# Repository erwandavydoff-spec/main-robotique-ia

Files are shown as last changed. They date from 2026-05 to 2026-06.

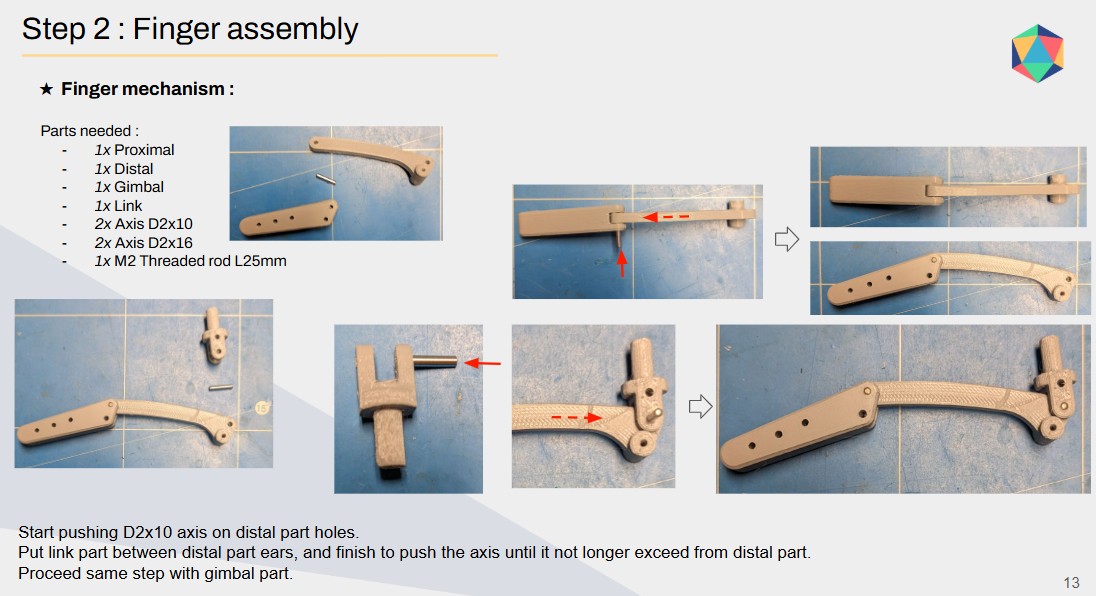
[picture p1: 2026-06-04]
assets/Assembly.jpg

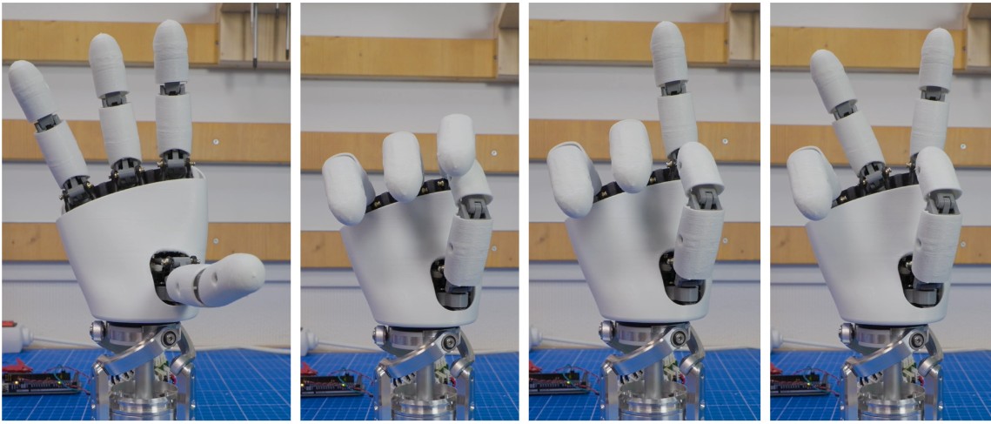
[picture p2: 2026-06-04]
assets/Patterns_Overview.jpg

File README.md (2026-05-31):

<div align="center">

Header

**Open-source robotic hand controlled by real-time AI hand tracking**









</div>

---

## Overview

**Main Robotique IA** is a fully functional robotic hand that replicates human finger movements in real time using a standard webcam and AI-based hand tracking.

A camera captures the user's hand. MediaPipe detects 21 3D landmarks on it. Python computes the flexion angle of each finger and sends the result to an ESP32 microcontroller over USB serial. The ESP32 drives five servo motors — one per finger — to mirror the gesture with minimal latency.

No cloud. No external API. Everything runs locally on consumer hardware.

> **Current state:** the full pipeline is operational end-to-end. The hand successfully replicates gestures captured by the camera in real time. Active work is focused on latency reduction, mechanical refinement, and auto-calibration.

---

## Demo

| Gesture captured | Hand response |
|---|---|
| Open hand | All 5 fingers extended |
| Closed fist | All 5 fingers retracted |
| Individual finger movement | Corresponding servo actuated |
| Dynamic gestures | Continuous real-time mirroring |

> Video demonstration coming in v1.0.

---

## System Architecture

### Full pipeline

```mermaid
flowchart LR
    A[📷 Webcam] --> B[OpenCV\nCapture]
    B --> C[MediaPipe\n21 Landmarks]
    C --> D[Python\nAngle Mapping]
    D -->|USB Serial\n115200 baud| E[ESP32\nFirmware]
    E --> F[5× Servo\nMotors]
    F --> G[🤖 Robotic\nHand]

    style A fill:#1e293b,stroke:#0ea5e9,color:#fff
    style B fill:#1e293b,stroke:#0ea5e9,color:#fff
    style C fill:#1e293b,stroke:#10b981,color:#fff
    style D fill:#1e293b,stroke:#3b82f6,color:#fff
    style E fill:#1e293b,stroke:#f59e0b,color:#fff
    style F fill:#1e293b,stroke:#f59e0b,color:#fff
    style G fill:#1e293b,stroke:#8b5cf6,color:#fff
```

### Layer breakdown

```mermaid
flowchart TB
    subgraph L1["🧠 Layer 1 — Vision & AI"]
        A[Webcam] --> B[OpenCV\nframe capture]
        B --> C[MediaPipe Hands\n21 landmarks x,y,z]
    end

    subgraph L2["⚙️ Layer 2 — Processing · Python"]
        D[Landmark array] --> E[Per-finger\nangle computation]
        E --> F[Normalize 0–180°]
        F --> G[Serialize command\nS1:90,S2:45,...]
        G --> H[PySerial write]
    end

    subgraph L3["🔌 Layer 3 — Embedded · ESP32"]
        I[UART reception] --> J[Command\nframe parser]
        J --> K[5× PWM output]
        K --> L[SG90 / MG996R\nservo actuation]
    end

    L1 --> L2
    L2 -->|USB / UART| L3
```

### Finger angle computation

```mermaid
flowchart LR
    A[Landmark 0\nWrist] --> D[Vector\ncomputation]
    B[Landmark MCP\nKnuckle] --> D
    C[Landmark TIP\nFingertip] --> D
    D --> E[Flexion angle\n0° – 180°]
    E --> F[PWM value\n500 – 2400 µs]
    F --> G[Servo position]
```

---

## Features

| Module | Description | Status |
|---|---|---|
| Hand tracking | 21-landmark detection via MediaPipe Hands | ✅ Operational |
| Finger angle mapping | Flexion angle extracted per finger | ✅ Operational |
| Serial bridge | Python ↔ ESP32 UART communication | ✅ Operational |
| Embedded firmware | 5-channel PWM servo driver on ESP32 | ✅ Operational |
| Real-time mirroring | Gesture replication via webcam | ✅ Operational |
| Latency optimization | Target < 50 ms end-to-end | 🔄 In Progress |
| 3D printed hand | Printable mechanical assembly | 🔄 In Progress |
| Auto-calibration | Servo range self-calibration | 📋 Planned |
| Visualization UI | Live landmark overlay + servo state | 📋 Planned |
| Multi-mode control | Mirror / preset / sequence modes | 📋 Planned |

---

## Tech Stack

| Layer | Technology | Role |
|---|---|---|
| Embedded | ESP32 + Arduino framework | PWM generation, UART reception |
| AI / Vision | MediaPipe Hands (Google) | 21-point 3D hand landmark detection |
| Computer Vision | OpenCV | Camera capture, frame preprocessing |
| Application | Python 3.8+ | Pipeline orchestration, serial I/O |
| Serial | PySerial | Python ↔ ESP32 data link |
| Numerics | NumPy | Landmark normalization, angle math |
| Actuation | SG90 / MG996R servo motors | Physical finger movement |
| Firmware | C / C++ | Low-level ESP32 control |

---

## Project Structure

```
main-robotique-ia/
│
├── esp32/
│   ├── main.ino                    # Arduino entry point
│   ├── servo_control.cpp           # 5-channel PWM driver
│   └── serial_parser.cpp           # Command frame parser
│
├── python/
│   ├── main_controller.py          # Pipeline entry point
│   ├── serial_bridge.py            # PySerial abstraction layer
│   └── gesture_mapper.py           # Landmark → servo angle
│
├── mediapipe/
│   ├── hand_tracker.py             # MediaPipe Hands wrapper
│   ├── landmark_analyzer.py        # Per-finger angle extraction
│   └── mediapipe_hand_tracking.py  # Standalone demo script
│
├── cad/
│   ├── fingers/                    # Phalanges and joint models
│   ├── palm/                       # Base plate model
│   └── assembly/                   # Full assembly instructions
│
├── docs/
│   ├── wiring_diagram.pdf          # ESP32 wiring reference
│   ├── servo_calibration.md        # Calibration procedure
│   └── architecture.md             # Detailed design notes
│
├── tests/
│   ├── servo_test.py               # Individual servo validation
│   └── latency_benchmark.py        # End-to-end latency measure
│
└── README.md
```

---

## Getting Started

### Prerequisites

- Python 3.8 or higher
- Arduino IDE 2.x or PlatformIO
- ESP32 DevKit v1 (or compatible board)
- USB webcam or built-in camera
- 5× SG90 or MG996R servo motors

### 1. Clone the repository

```bash
git clone https://github.com/USERNAME/main-robotique-ia.git
cd main-robotique-ia
```

### 2. Install Python dependencies

```bash
pip install opencv-python mediapipe pyserial numpy
```

### 3. Flash the ESP32

Open `esp32/main.ino` in Arduino IDE, select **ESP32 Dev Module** as the target board, and upload via USB.

### 4. Configure the serial port

```python
# python/serial_bridge.py
SERIAL_PORT = "/dev/ttyUSB0"   # Linux / macOS
SERIAL_PORT = "COM3"            # Windows
BAUD_RATE   = 115200
```

### 5. Run

```bash
python python/main_controller.py --port COM3 --baud 115200
```

---

## Usage

```bash
# Full pipeline (camera → AI → ESP32 → hand)
python python/main_controller.py --port COM3 --baud 115200

# Camera + AI only, no hardware required
python mediapipe/mediapipe_hand_tracking.py

# Test servo actuation independently
python tests/servo_test.py

# Measure end-to-end latency
python tests/latency_benchmark.py
```

---

## How It Works

1. **Capture** — OpenCV reads frames from the webcam at ~30 fps.
2. **Detection** — MediaPipe Hands processes each frame and returns 21 3D landmarks representing key points on the hand (fingertips, knuckles, wrist).
3. **Analysis** — For each finger, the relative positions of its three landmarks are used to compute a flexion angle between 0° (fully extended) and 180° (fully closed).
4. **Encoding** — The five angles are packed into a compact serial command: `S1:90,S2:45,S3:120,S4:60,S5:30\n`
5. **Transmission** — PySerial sends the command to the ESP32 at 115200 baud over USB.
6. **Actuation** — The ESP32 firmware parses the frame and writes the corresponding PWM signal to each servo motor.
7. **Mirroring** — The robotic hand replicates the detected gesture. The loop repeats every frame.

---

## Provisional Development Planning

The full development planning is available as a structured Excel file with three sheets: **Planning Général** (all phases and tasks), **Gantt Chart** (visual Jan → Oct 2025 timeline), and **Tâches Détaillées** (26 numbered tasks with technical notes).

📥 **[Download Planning_MainRobotiqueIA.xlsx](./docs/Planning_MainRobotiqueIA.xlsx)**

---

### Roadmap

```mermaid
gantt
    title Main Robotique IA — Development Roadmap 2025
    dateFormat  YYYY-MM-DD
    section Phase 1 · Core Pipeline
    MediaPipe integration          :done,    2025-01-01, 2025-02-15
    ESP32 firmware                 :done,    2025-01-15, 2025-02-28
    Python serial bridge           :done,    2025-02-01, 2025-03-10
    End-to-end functional test     :done,    2025-03-01, 2025-03-20
    section Phase 2 · Performance
    Latency profiling              :active,  2025-03-20, 2025-04-30
    Frame rate optimization        :active,  2025-04-01, 2025-05-15
    Serial error handling          :active,  2025-04-15, 2025-05-30
    Servo jitter & latency <50ms   :         2025-05-01, 2025-06-15
    section Phase 3 · Mechanics
    Finger & joint 3D models       :active,  2025-04-01, 2025-06-01
    Palm base plate                :active,  2025-05-01, 2025-06-30
    Servo mounting + tendons       :         2025-06-01, 2025-07-31
    Printable STL release          :         2025-08-01, 2025-08-15
    section Phase 4 · Calibration & Modes
    Auto servo calibration         :         2025-07-15, 2025-08-15
    Preset & sequence modes        :         2025-08-01, 2025-09-30
    section Phase 5 · Interface & Release
    Visualization overlay          :         2025-09-01, 2025-09-30
    Full documentation             :         2025-09-01, 2025-10-15
    Demo video + v1.0 release      :milestone, 2025-10-31, 2025-10-31
```

### Progress summary

| Phase | Objective | Progress | ETA |
|---|---|---|-----|
| Phase 1 · Core Pipeline | Camera → AI → ESP32 → Hand | ✅ 100% | Done |
| Phase 2 · Performance | Latency < 50ms, 30+ fps | 🔄 40% | Jun 2025 |
| Phase 3 · Mechanics | Printable 3D hand assembly | 🔄 15% | Jul 2025 |
| Phase 4 · Calibration | Auto-calibration, control modes | 📋 0% | Aug 2025 |
| Phase 5 · Interface & Release | Visualization, docs, v1.0 | 📋 0% | Oct 2025 |

---

## Authors

**Lead developer** — Bac Pro CIEL student, self-taught in robotics, AI, and embedded systems.

**Collaborator** — [MSBruno0088](https://github.com/MSBruno0088) — development and integration.

---

## License

Distributed under an open-source license. Free to use for educational and experimental purposes.

---

<div align="center">
<sub>Main Robotique IA — real-time interaction between artificial intelligence and robotic systems.</sub>

Footer
</div>

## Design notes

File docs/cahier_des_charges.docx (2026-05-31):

CAHIER DES CHARGES

Main Robotique IA

Projet Bac Pro CIEL · 2024–2025

📅 Version : 2.0 · Juin 2025

👥 Équipe : Prince, Alexandre, Bruno, Erwan

🏫 Formation : 1re CIEL — Bac Pro CIEL

📌 Statut : En développement

# 1. Contexte et présentation

Nous sommes en première CIEL (Cybersécurité, Informatique et réseaux, ÉLectronique). Dans le cadre du Bac Professionnel CIEL, nous devons réaliser un projet technique sur deux années afin d'acquérir et de valider des compétences transversales en programmation, en électronique et en mécanique, tout en pratiquant la gestion de projet en équipe.

Le projet "Main Robotique IA" consiste à concevoir et réaliser une main robotique open-source capable de reproduire les mouvements d'une main humaine en temps réel, à partir de plusieurs modalités de détection : vision artificielle par MediaPipe et capteurs électromyographiques (EMG). Ce projet nous permet de combiner des compétences en intelligence artificielle embarquée, en traitement du signal, en mécatronique et en fabrication additive.

# 2. Équipe du projet

Collaborateur | Rôle principal
Prince | Lead développeur · Pipeline vision IA · Intégration EMG
Alexandre | Électronique · Firmware ESP32 · PWM et ADC EMG
Bruno | Mécanique · Modélisation CAO 3D · Impression et tendons
Erwan | Intégration système · Tests · Documentation technique

# 3. Liste des composants

## 3.1 Électronique et microcontrôleur

- 1× ESP32 DevKit v1 — microcontrôleur principal dual-core 240 MHz (Wi-Fi, Bluetooth, ADC 12 bits)
- 5× Servomoteurs SG90 180° — pour les doigts (index, majeur, annulaire, auriculaire)
- 1× Servomoteur MG996R 180° — pour le pouce (couple plus élevé)
- 1× Module alimentation MB102 — 5V/3A pour les servos, 3.3V pour l'ESP32 et l'EMG
- 1× Condensateur 1000 µF — filtrage anti-bruit sur l'alimentation des servos
- Fils de connexion jumper Male-Male et Male-Female
- 1× Breadboard ou PCB personnalisé pour le câblage

## 3.2 Capteurs EMG — Électromyographie

💪 NOUVEAUTÉ : Capteurs EMG pour la détection musculaire directe

- 5× Capteurs EMG MyoWare 2.0 (SparkFun) — 1 par doigt / groupe musculaire de l'avant-bras
- 15× Électrodes Ag/AgCl adhésives jetables (3 par capteur : +, –, référence)
- 1× Câble de blindage pour minimiser les interférences 50 Hz du secteur
- 1× Bande élastique de maintien des capteurs sur l'avant-bras

## 3.3 Vision par ordinateur

- 1× Webcam USB 1080p à 30 fps minimum (Logitech C270 ou équivalent)
- 1× PC ou laptop sous Windows/Linux avec Python 3.8+ et OpenCV installé
- 1× Câble USB-C pour la liaison PC ↔ ESP32

## 3.4 Mécanique et fabrication

- 1× Imprimante 3D FDM (Ender 3 ou équivalent) pour les pièces en PLA
- Filament PLA 1.75 mm (blanc ou gris) — ~200g pour la main complète
- Fil de pêche nylon 0.3 mm — tendons pour la flexion des doigts
- 20× Vis M2×8 mm + écrous M2 — assemblage mécanique
- 5× Ressorts de rappel 5 mm — pour l'extension passive des doigts
- 1× Plaque de base en PLA ou aluminium pour fixer les servos

# 4. Besoin principal et objectifs

L'objectif fondamental du projet est de reproduire fidèlement les mouvements des doigts d'une main humaine sur une main robotique, en temps réel et avec une latence inférieure à 50 ms entre la détection du geste et l'actionnement du servo correspondant.

Le système combine deux modalités de détection :

- Vision par ordinateur : MediaPipe Hands détecte 21 landmarks 3D sur la main et calcule les angles de flexion de chaque doigt depuis les images de la webcam.
- Électromyographie (EMG) : les capteurs MyoWare 2.0 placés sur l'avant-bras captent l'activité électrique des muscles fléchisseurs, permettant une détection même sans ligne de vue directe sur la main.
- Fusion des deux modalités : un algorithme de fusion pondérée (60% vision / 40% EMG par défaut) combine les deux sources pour une robustesse maximale dans toutes les conditions.

Les cinq angles calculés sont encodés et transmis à l'ESP32 via USB série (UART à 115200 baud). L'ESP32 génère les signaux PWM correspondants pour chaque servomoteur, reproduisant ainsi le geste capturé.

# 5. Résultat attendu

## 5.1 Fonctionnalités cibles

Fonctionnalité | Critère d'acceptation
Reproduction des gestes | Les 5 doigts suivent la main humaine en temps réel
Latence système | < 50 ms de bout en bout (capture → servo)
Fréquence de mise à jour | ≥ 25 fps (pipeline vision + EMG)
Précision angulaire | ± 5° de précision par servo
Gestes prédéfinis | Fermer le poing, pointer, signe "V", pouce levé
Mode EMG seul | Fonctionnement sans caméra (main occultée)
Mode vision seul | Fonctionnement sans capteurs EMG
Mode fusion | Combinaison des deux modalités (défaut)
Stabilité continue | Fonctionnement stable 30 min sans erreur

## 5.2 Interface logicielle

- Overlay temps réel : visualisation des landmarks MediaPipe, des angles calculés et de l'état des servos sur la fenêtre de la caméra
- Indicateurs EMG : affichage de l'amplitude RMS de chaque canal EMG en temps réel
- Configuration YAML : fichier de paramétrage pour les ports série, les seuils EMG, les plages servo et le mode de fonctionnement
- Logs CSV : enregistrement des angles et des latences pour analyse a posteriori

# 6. Architecture technique

## 6.1 Pipeline vision (MediaPipe)

Étape | Technologie
1. Capture vidéo | OpenCV — lecture webcam 30 fps
2. Détection landmarks | MediaPipe Hands — 21 points 3D
3. Calcul angles | NumPy — produit scalaire sur vecteurs
4. Encodage trame | Python — format S1:90,S2:45,...
5. Transmission | PySerial — UART 115200 baud
6. Actionnement | ESP32 C++ — driver PWM 500–2400 µs

## 6.2 Pipeline EMG (MyoWare 2.0)

Étape | Détail technique
1. Acquisition analogique | MyoWare 2.0 → ADC 12 bits ESP32 ou ADS1115 via I2C
2. Filtrage numérique | Passe-bande 20–450 Hz + Notch 50 Hz (SciPy)
3. Extraction de features | RMS, Zero Crossing Rate, Mean Absolute Value
4. Classification | SVM ou CNN 1D (TensorFlow Lite) — 5 classes de geste
5. Normalisation | Angles 0–180° depuis les features EMG normalisées

## 6.3 Fusion multi-modale

La fusion des deux modalités est réalisée par une pondération adaptive :

- Poids vision (α) = 0.6 par défaut, augmente si la main est bien visible (confidence MediaPipe > 0.8)
- Poids EMG (β) = 0.4 par défaut, augmente si la main est occultée ou peu éclairée
- Formule : angle_final = α × angle_vision + β × angle_emg

# 7. Applications potentielles

Icône | Application | Description
🏥 | Rééducation médicale | Aide les patients à retrouver la motricité fine, suivi des progrès en temps réel
🦾 | Prothèses intelligentes | Base technologique pour des mains artificielles contrôlées par signaux EMG naturels
🎓 | Robotique éducative | Apprentissage de la programmation, de l'IA et de l'électronique embarquée
🎮 | Interface homme-machine | Contrôle de jeux vidéo, robots ou systèmes à distance par gestes
🔬 | Recherche en neurosciences | Étude des signaux EMG et de la coordination main-cerveau

# 8. Problématiques et défis techniques

### ⚡ Latence temps réel

Maintenir une latence < 50 ms entre détection et actionnement. Optimisation du pipeline Python, réduction des allocations mémoire, utilisation de threads séparés pour la capture vidéo et l'envoi série.

### 💪 Qualité du signal EMG

Le signal EMG brut est bruité (interférences 50 Hz, artefacts de mouvement). Nécessite un filtrage passe-bande strict et un blindage des câbles. La calibration par utilisateur est indispensable.

### 🧠 Calibration des capteurs EMG

Chaque utilisateur a des signaux EMG différents selon la morphologie, la fatigue et le placement des électrodes. Phase de calibration initiale de 2–3 minutes avec gestes de référence.

### 🔩 Limites mécaniques des servos

Les SG90 ont un couple limité (~1.8 kg·cm). La conception du système tendineux doit minimiser les frottements et la résistance mécanique pour rester dans les limites du servo.

### 🔗 Fusion multi-modale

Combiner deux sources de données avec des délais et des dynamiques différents (EMG : signal musculaire avant le mouvement, vision : pendant le mouvement) nécessite une synchronisation temporelle précise.

### 🔋 Alimentation et bruit

Les servos consomment jusqu'à 1A en charge. L'alimentation doit être propre et dimensionnée. Les capteurs EMG sont très sensibles au bruit d'alimentation (résistance < 1 Ω recommandée).

# 9. Planning prévisionnel 2025

Phase | Période | Avancement | Livrable
Phase 1 · Pipeline Principal | Jan – Mar 2025 | ✅ 100% | Pipeline fonctionnel bout en bout
Phase 2 · Stabilité & Performance | Mar – Jun 2025 | 🔄 40% | Latence < 50ms, 30+ fps
Phase 3 · Mécanique 3D | Avr – Aoû 2025 | 🔄 15% | Fichiers STL release
Phase 4 · Intégration EMG | Mai – Aoû 2025 | 📋 0% | EMG fusionné avec vision
Phase 5 · Calibration & Modes | Aoû – Sep 2025 | 📋 0% | Config YAML + modes
Phase 6 · Release v1.0 | Oct – Nov 2025 | 📋 0% | Docs + vidéo + GitHub release

# 10. Glossaire

Terme | Définition
EMG / Électromyographie | Mesure de l'activité électrique générée par les muscles lors de leur contraction. Signal de 0.1–10 mV, fréquences 20–450 Hz.
MediaPipe Hands | Framework Google de vision par ordinateur détectant 21 landmarks 3D sur la main en temps réel via une caméra standard.
PWM (Pulse Width Modulation) | Signal à largeur d'impulsion variable utilisé pour contrôler la position d'un servomoteur (500–2400 µs pour 0–180°).
ESP32 | Microcontrôleur Espressif dual-core Xtensa LX6 240 MHz. Intègre Wi-Fi, Bluetooth, ADC 12 bits, DAC, UART, SPI, I2C.
UART | Bus série asynchrone (TX/RX). Utilisé pour la communication Python ↔ ESP32 à 115200 bauds.
RMS (Root Mean Square) | Valeur efficace d'un signal AC. Utilisée comme feature principale pour quantifier l'intensité musculaire EMG.
DSP (Digital Signal Processing) | Traitement numérique du signal. Ici : filtrage, fenêtrage, extraction de features sur le signal EMG brut.
CNN 1D | Réseau de neurones convolutif à une dimension. Utilisé pour classifier les gestes depuis les séquences de signal EMG.
Tendon (robotique) | Câble en nylon reliant le servo au doigt de la main robotique, transmettant la force de traction pour la flexion.
Landmark | Point de repère 3D (x, y, z) sur la main détecté par MediaPipe. 21 landmarks couvrent poignets, articulations et bouts de doigts.

Main Robotique IA — Cahier des Charges v2.0 — Juin 2025 — Bac Pro CIEL

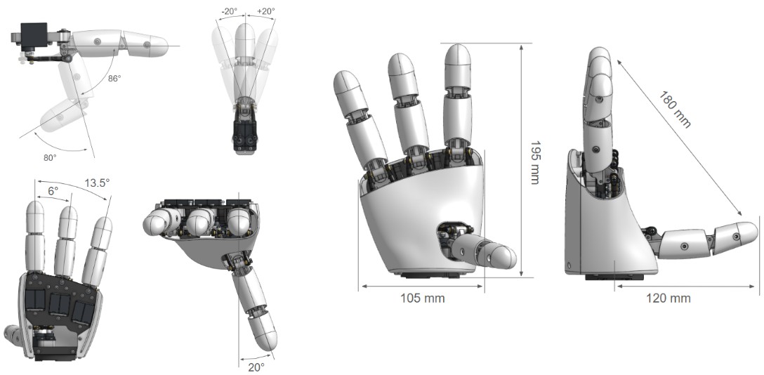
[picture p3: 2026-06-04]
assets/Hand_Overview.jpg

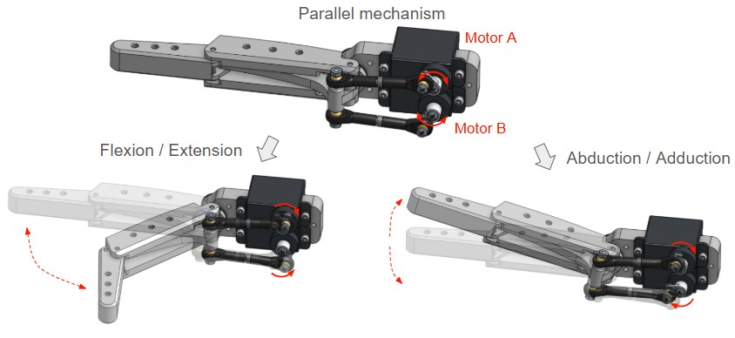
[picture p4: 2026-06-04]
assets/Finger_Overview.jpg

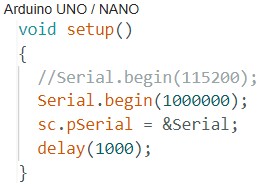
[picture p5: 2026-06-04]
assets/Arduino_Uno.jpg

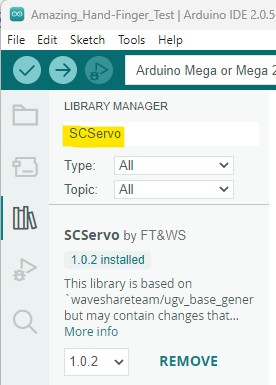
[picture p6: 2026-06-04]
assets/SCServo.jpg

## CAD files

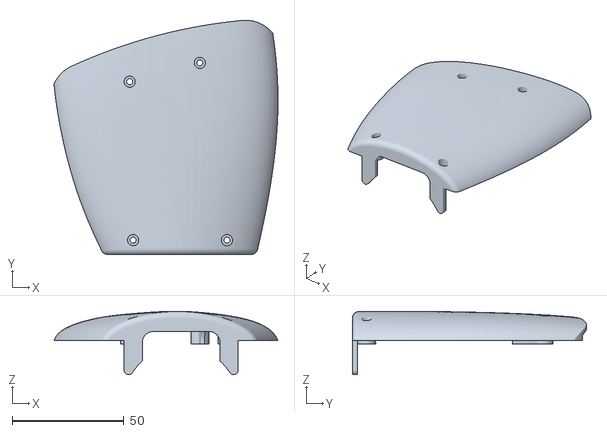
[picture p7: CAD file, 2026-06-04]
cad/stl/Amazing Hand Parts - L-Top_Shell.stl
100.2 x 104.9 x 28.4

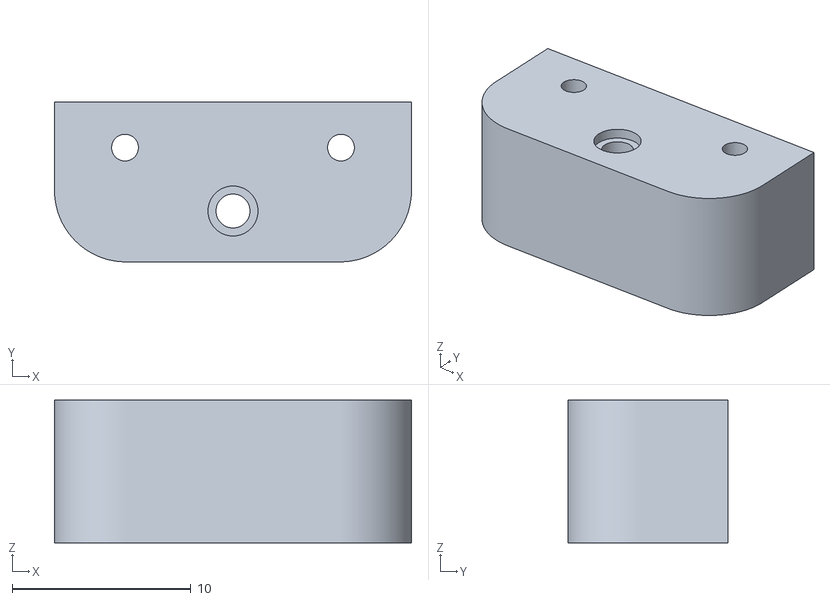
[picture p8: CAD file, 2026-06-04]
cad/stl/Amazing Hand Parts - Finger_Frame-2.stl
20.0 x 8.95 x 8.00

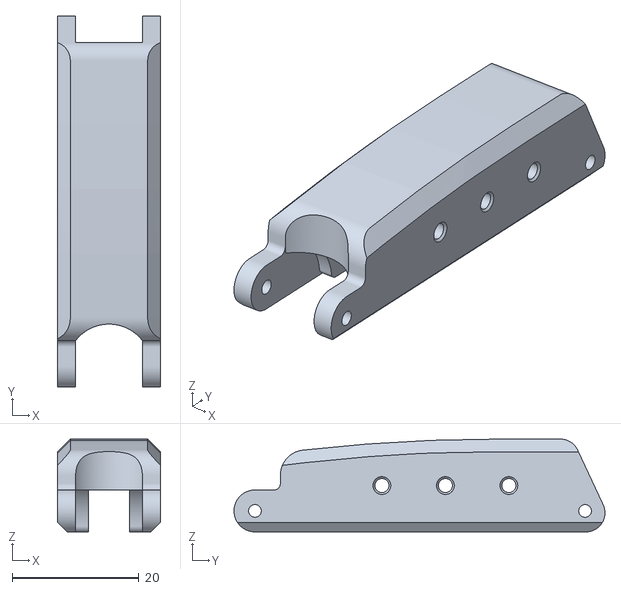
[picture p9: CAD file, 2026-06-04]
cad/stl/Amazing Hand Parts - Proximal.stl
16.2 x 58.4 x 14.6

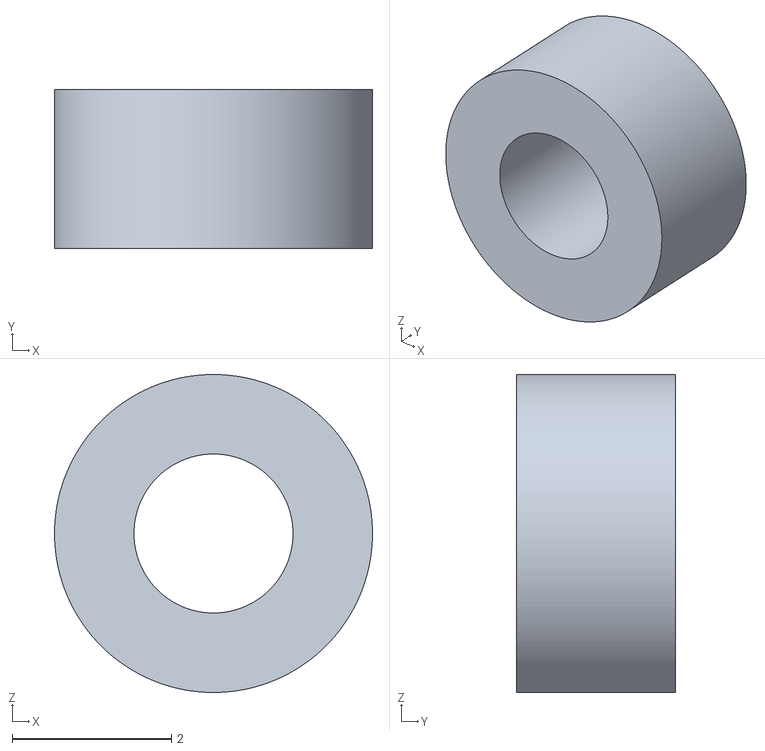
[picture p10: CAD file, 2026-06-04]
cad/stl/BallJoint_Rod - Spacer.stl
4.00 x 2.00 x 4.00

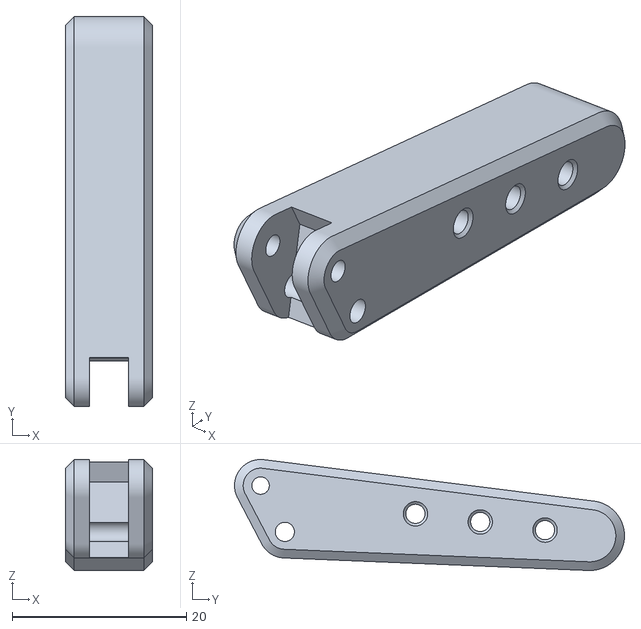
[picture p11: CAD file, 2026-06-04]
cad/stl/Amazing Hand Parts - Distal.stl
10.0 x 44.8 x 12.8

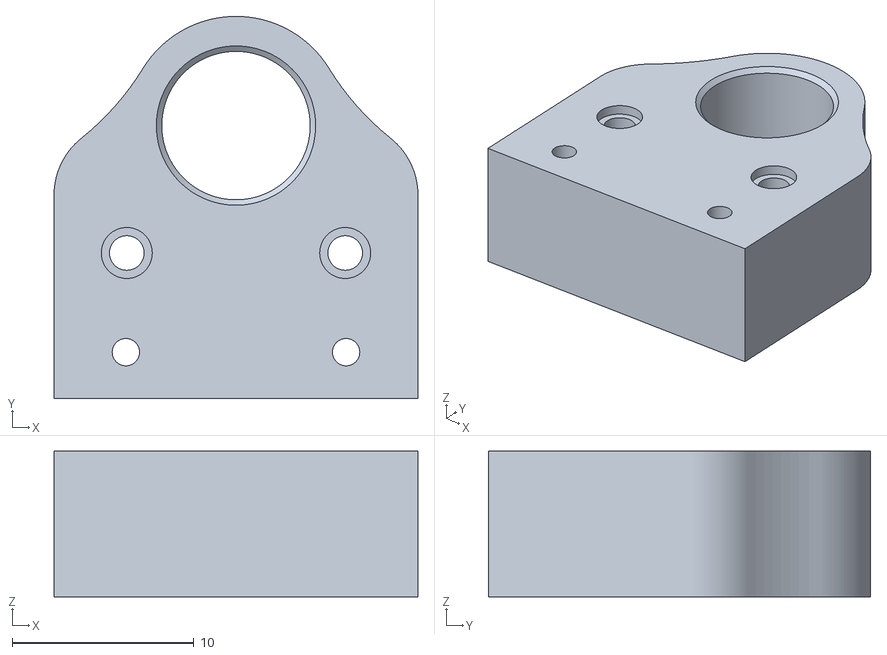
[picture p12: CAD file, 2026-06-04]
cad/stl/Amazing Hand Parts - Finger_Frame-1.stl
20.0 x 21.0 x 8.00

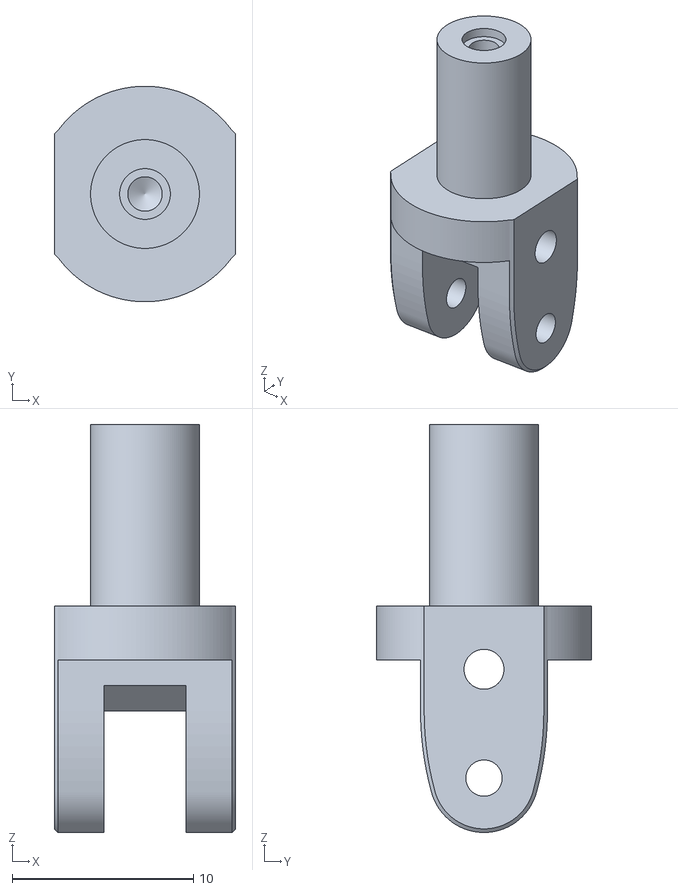
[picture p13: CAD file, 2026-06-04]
cad/stl/Amazing Hand Parts - Gimbal.stl
10.0 x 11.9 x 22.5

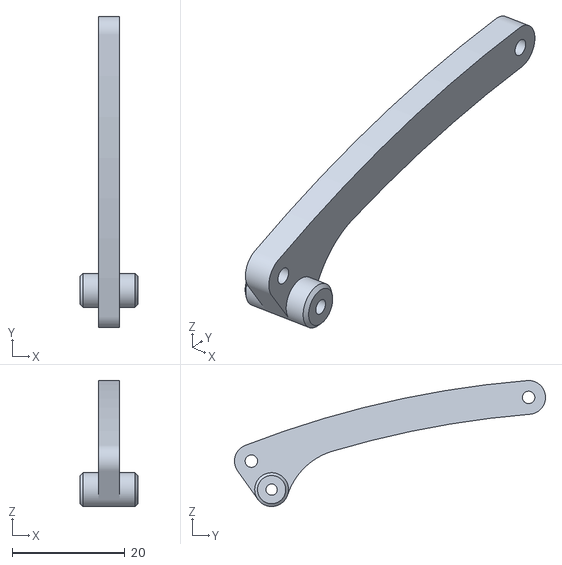
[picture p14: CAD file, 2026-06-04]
cad/stl/Amazing Hand Parts - Link.stl
10.3 x 55.2 x 22.4

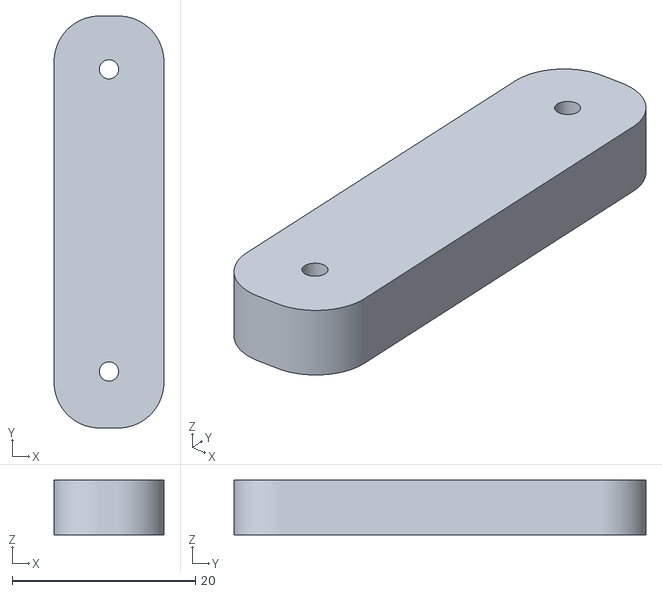
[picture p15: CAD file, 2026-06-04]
cad/stl/BallJoint_Rod - Length_Toolings.stl
12.0 x 45.0 x 6.00

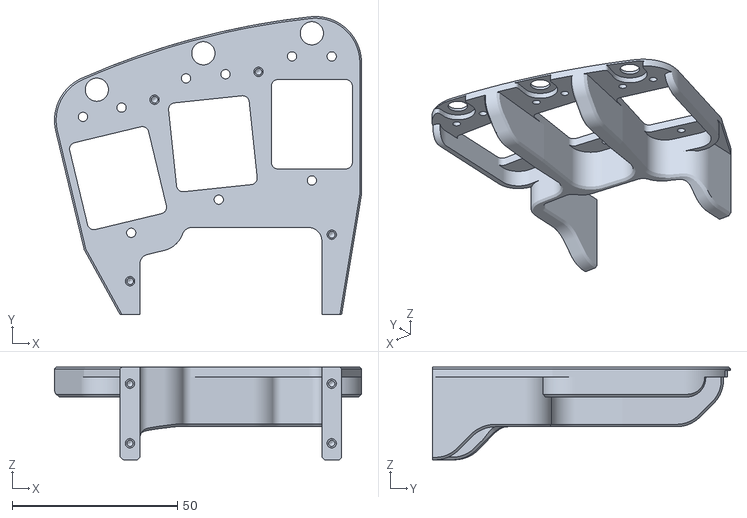
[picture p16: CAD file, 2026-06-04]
cad/stl/Amazing Hand Parts - L-Hand_Plate.stl
92.8 x 90.1 x 28.0

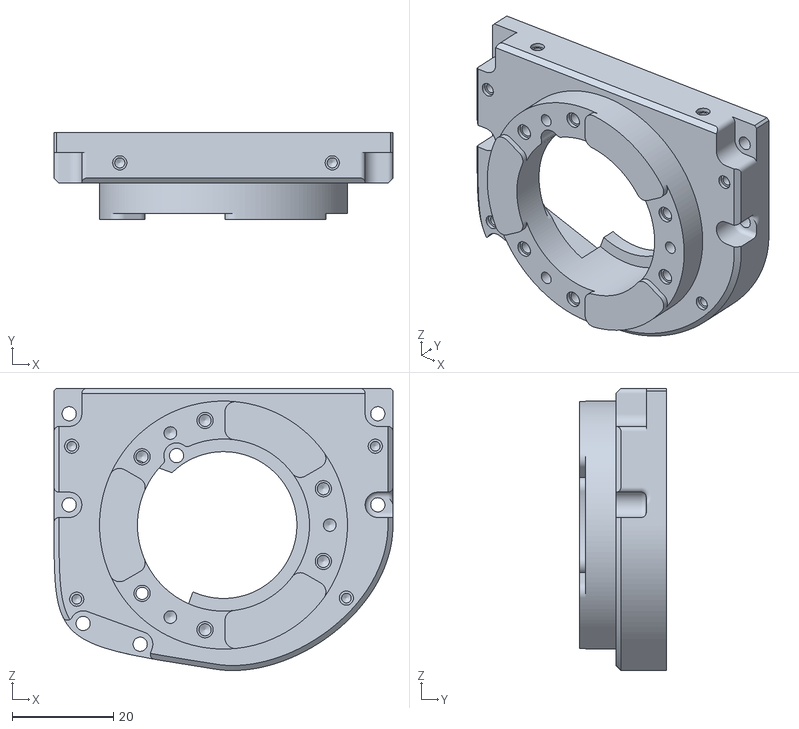
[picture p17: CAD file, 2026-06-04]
cad/stl/Amazing Hand Parts - R-Wrist_Interface.stl
67.0 x 17.2 x 55.8

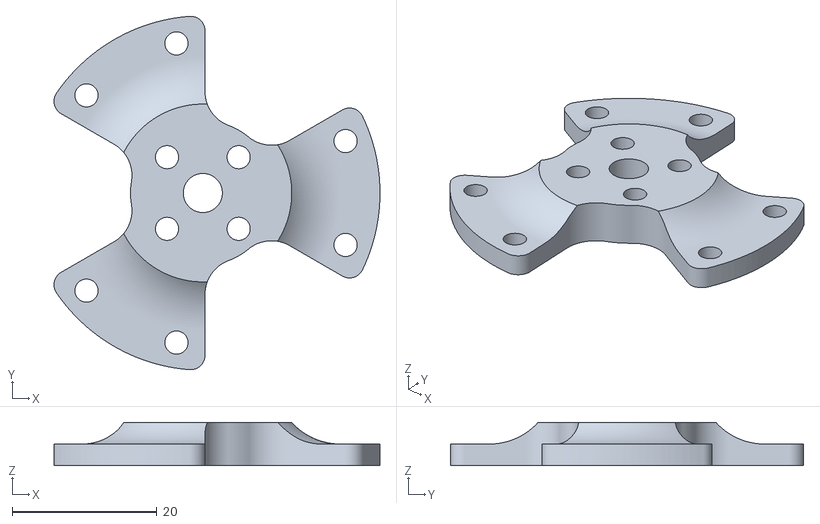
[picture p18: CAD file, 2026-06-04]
cad/stl/SO-ARM_Interface.stl
45.1 x 48.9 x 6.00

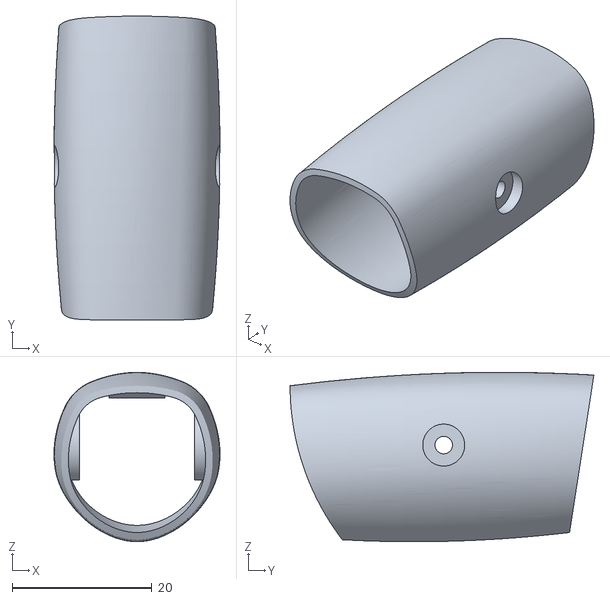
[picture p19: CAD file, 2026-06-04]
cad/stl/Amazing Hand Parts - Proximal_Shell.stl
23.8 x 43.5 x 24.3

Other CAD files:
cad/stl/Amazing Hand Parts - R-Top_Shell.stl
cad/stl/Amazing Hand Parts - R-Hand_Plate.stl
cad/stl/Amazing Hand Parts - L-Wrist_Interface.stl

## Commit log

2026-02-15 Rename Arm_Cover.stl to Protection du bras.stl
2026-02-15 Update and rename main_droistl to main_droite.stl
    [main_droite.stl]
2026-03-19 cahier des charges
    [Bras.stl, Doigt_Annulaire_main.stl, Doigt_Auriculaire_Main.stl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]
2026-04-02 circuit thinkercard
2026-04-02 detection de mouvement py
2026-04-02 circuit kicad
    [circuit.kicad_sch]
2026-04-02 Rename Designer.png to circuit kicad.png
2026-04-02 circuit kicad.png
2026-04-06 débout de la page d'accueil
    [circuit.kicad_sch]
2026-04-23 page cahier de charges
    [circuit_pcb.kicad_pcb]
2026-04-30 cahier des charges debout

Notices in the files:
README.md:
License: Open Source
